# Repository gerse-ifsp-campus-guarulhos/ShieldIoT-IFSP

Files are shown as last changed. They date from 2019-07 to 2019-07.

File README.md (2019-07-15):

# ShieldIoT-IFSP

Licença: GNU GPL 2

Autores: [Pedro Igor Borçatti da Silva](https://github.com/pedro-ibs)

This program is free software; you can redistribute it and/or
modify it under the terms of the GNU General Public License as
published by the Free Software Foundation; version 2 of the
License.

This program is distributed in the hope that it will be useful,
but WITHOUT ANY WARRANTY; without even the implied warranty of
MERCHANTABILITY or FITNESS FOR A PARTICULAR PURPOSE.  See the
GNU General Public License for more details.

---

O SHIELD IoT-IFSP é uma placa didática criada para a plataforma NodeMCU (ESP8266) de baixo custo, desenvolvida para o ensino de lógica de programação aplicada à robótica e Iot (internet das coisas), cujo principal objetivo é facilitar o ensino de lógica de programação.

Neste Repositório se encontra todos os arquivos necessários para o **DESENVOLVIMENTO e DOCUMENTAÇÃO** para a **Shield IoT**, não Existe exemplos e programas testes para essa versão embora versões anteriores já tenham sido testadas (e falharam em algum ponto) no entanto esta versão está aparentemente está tudo certo, ela leva correções eletrônicas e de layout.

Na pasta [PCB](PCB/) estão os arquivos para fabricação da placa, tanto o [GERBER](PCB/GERBER/) para fabricação manufaturada, e um [PDF](PCB/PCB.pdf) para fabricação manual por transferência térmica. Em [Documentação](Documentação/) temos os arquivos referente ao circuito, lá encontrado o BOM (lista de componentes, e em formato ods feito pelo libreoffice), O [esquema elétrico](Documentação/esquematico.pdf) em pdf e o [arquivos do kicad](Documentação/Circuito/) e suas dependências.

# Uso dos pinos atual:
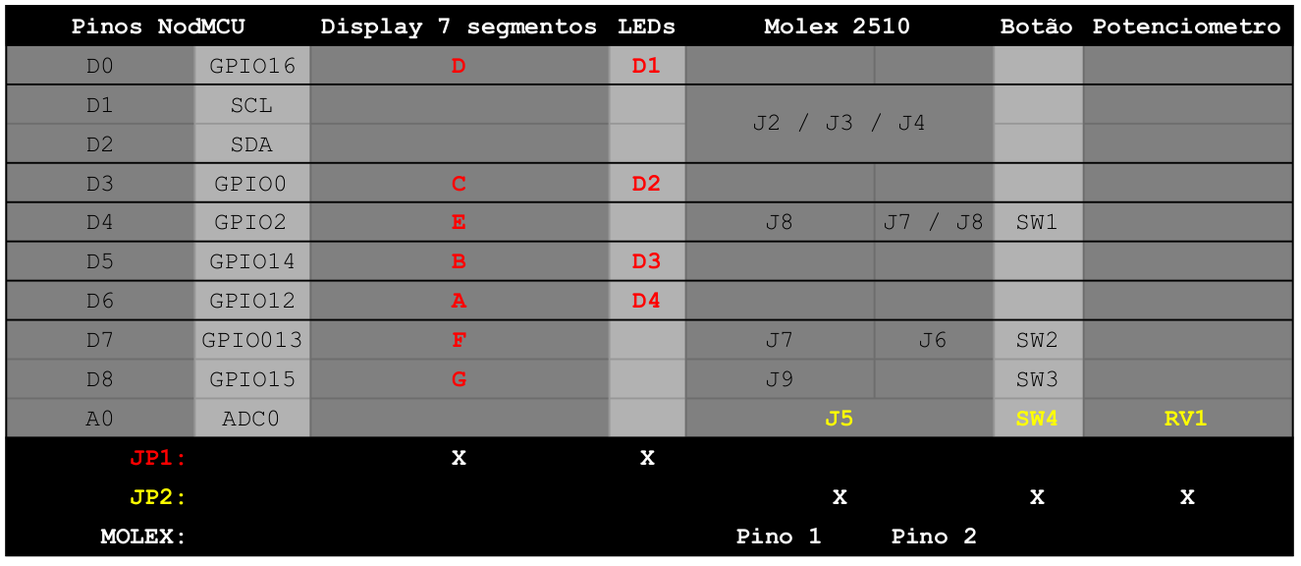
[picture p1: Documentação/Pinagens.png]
foto antiga


# O que precisa ser feio
* Testar placa, e todos os periféricos disponíveis para uso;
* Fazer um manual como a [Shield Edu-IFSP ](https://github.com/gerse-ifsp-campus-guarulhos/ShieldEdu-IFSP);
* programa testes como o [Exemplo da Shield Edu-IFSP](https://github.com/gerse-ifsp-campus-guarulhos/ShieldEdu-IFSP/tree/master/Exemplos);
* Criar artigos e publicações.

# Versão antiga

Está é a foto da versão antiga da placa porem existe em algum lugar no gerse a mesma versão dos arquivos desse repositório construída por transferência térmica

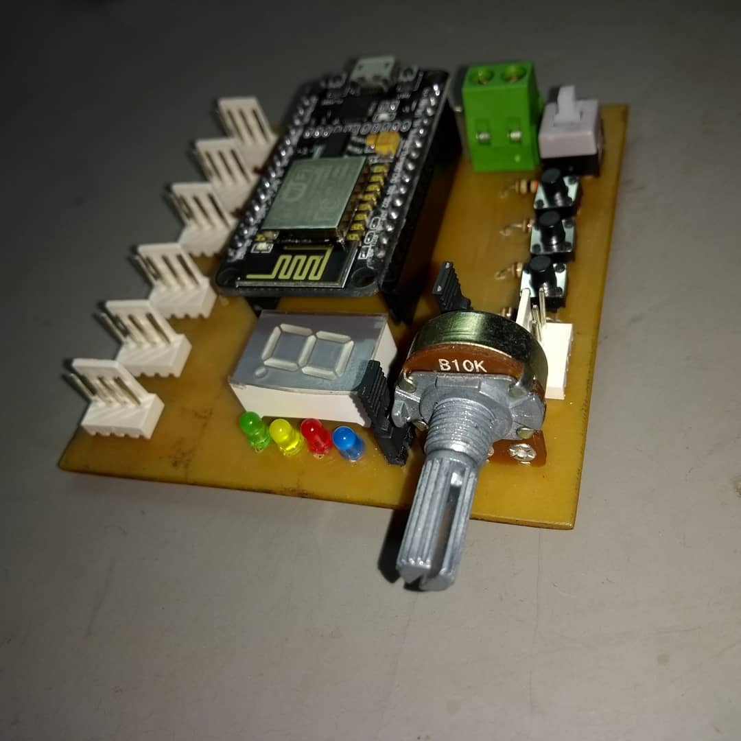
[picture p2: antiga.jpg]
versão antiga


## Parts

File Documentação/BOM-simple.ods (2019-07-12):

Referencia | Valor | Footprint | Quantidade
D1 – D4 | LED_ALT | MyFootprint:LED_D3.0mm | 4
D5 | 1N4007 | Diodes_THT:D_A-405_P5.08mm_Vertical_AnodeUp | 1
IC1 | NODEMCU | MyFootprint:NODEMCU2 | 1
J1 | VCC | MyFootprint:AK300-2 | 1
J2 - J4 | I2C | MyFootprint:molex_2510 | 3
J5 | VAIN | MyFootprint:molex_2510 | 1
J6 - J8 | OUT | MyFootprint:molex_2510 | 3
JP1, JP2 | JUMP3 | MyFootprint:Pin_Header_Straight_1x03 | 2
R2, R3 | 10K | MyFootprint:Resistor_Vertical_RM7mm | 2
R1 - R13 | 10K | Resistors_THT:R_Axial_DIN0207_L6.3mm_D2.5mm_P10.16mm_Horizontal | 4
R5 - R11 | 470 | MyFootprint:Resistor_Vertical_RM7mm | 7
RV1 | R_POT | MyFootprint:Potentiometer_Alps-RK16-single_largePads | 1
SW1 | BT1 | MyFootprint:BUTTON2P | 1
SW2, SW4 | BT2 | MyFootprint:BUTTON2P | 2
SW3 | SP6T | MyFootprint:SW_PUSH_x2 | 1
U1 | KCSA02-107 | MyFootprint:7SegmentLED_LTS6760_LTS6780-2 | 1

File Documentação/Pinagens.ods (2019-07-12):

Pinos NodMCU |  | Display 7 segmentos | LEDs | Molex 2510 |  | Botão | Potenciometro
D0 | GPIO16 | D | D1
D1 | SCL |  |  | J2 / J3 / J4
D2 | SDA
D3 | GPIO0 | C | D2
D4 | GPIO2 | E |  | J8 | J7 / J8 | SW1
D5 | GPIO14 | B | D3
D6 | GPIO12 | A | D4
D7 | GPIO013 | F |  | J7 | J6 | SW2
D8 | GPIO15 | G |  | J9 |  | SW3
A0 | ADC0 |  |  | J5 |  | SW4 | RV1
JP1: |  | X | X
JP2: |  |  |  | X |  | X | X
MOLEX: |  |  |  | Pino 1 | Pino 2

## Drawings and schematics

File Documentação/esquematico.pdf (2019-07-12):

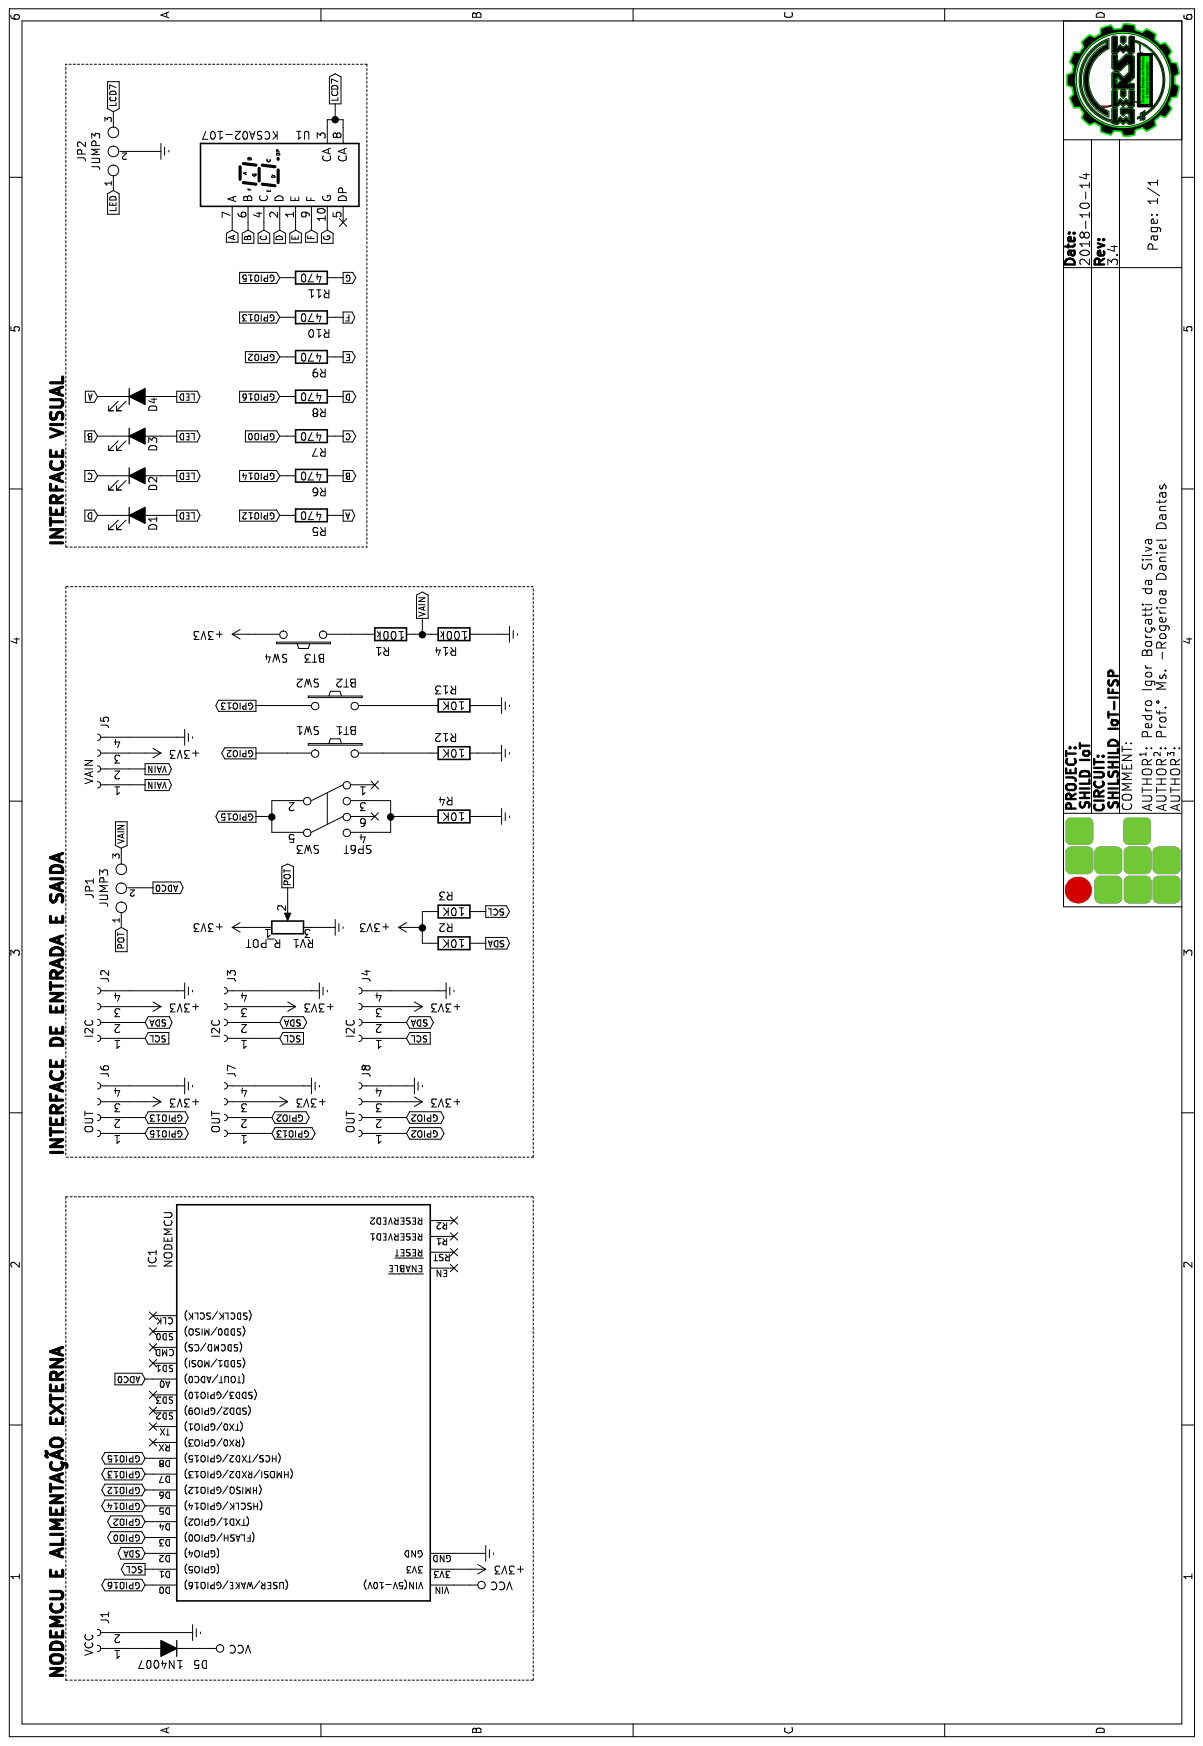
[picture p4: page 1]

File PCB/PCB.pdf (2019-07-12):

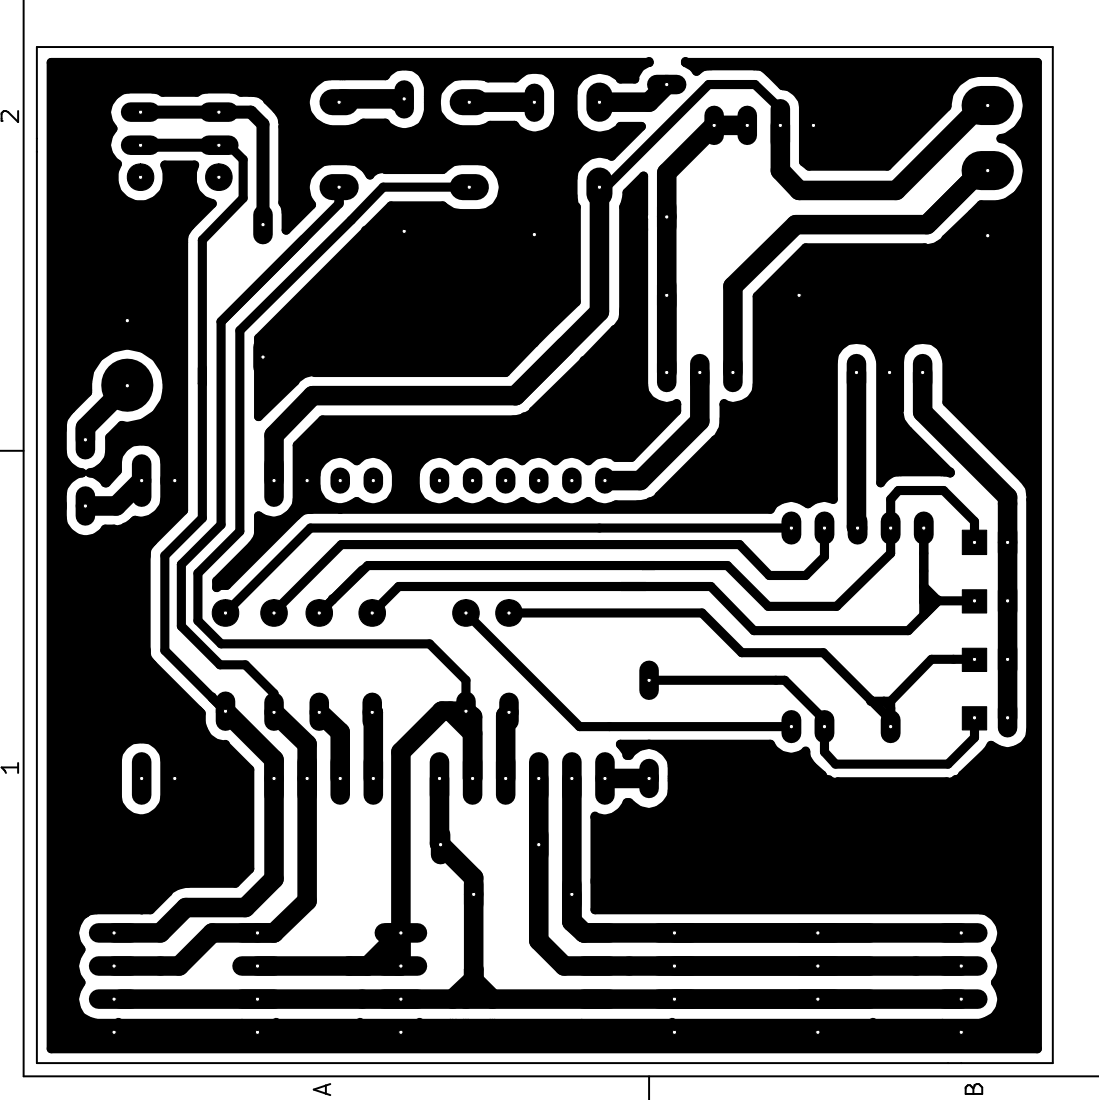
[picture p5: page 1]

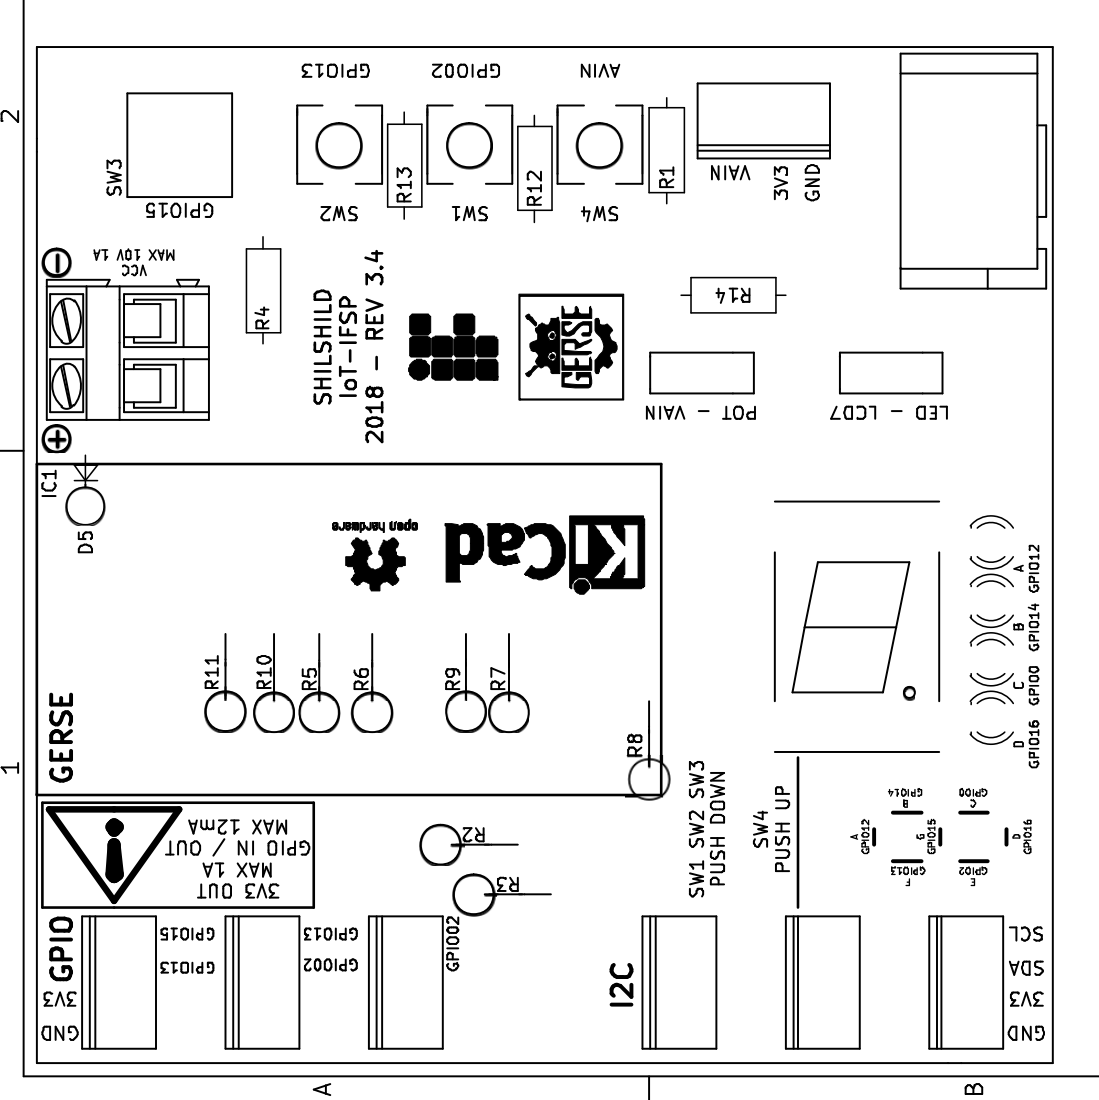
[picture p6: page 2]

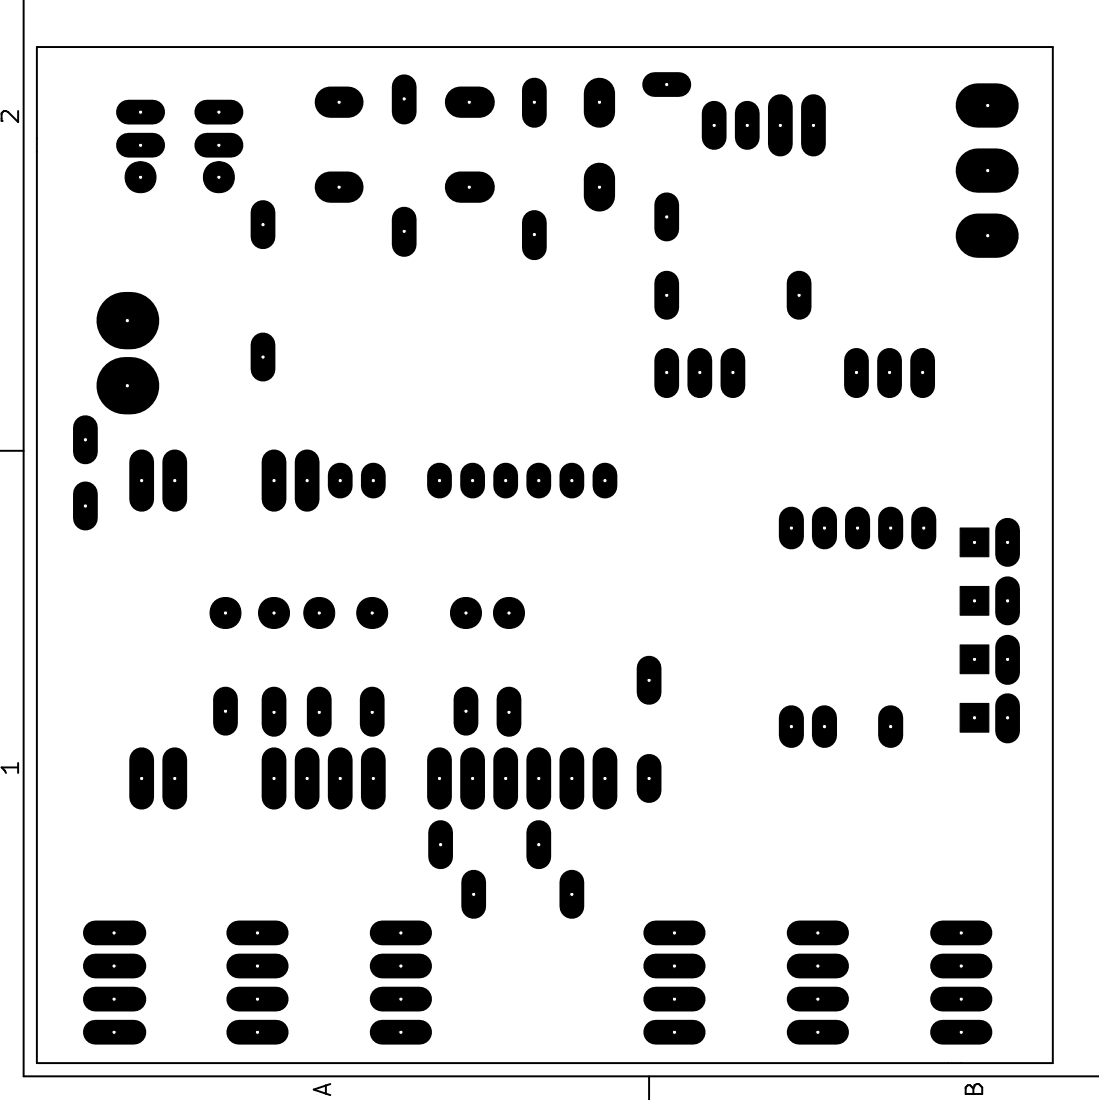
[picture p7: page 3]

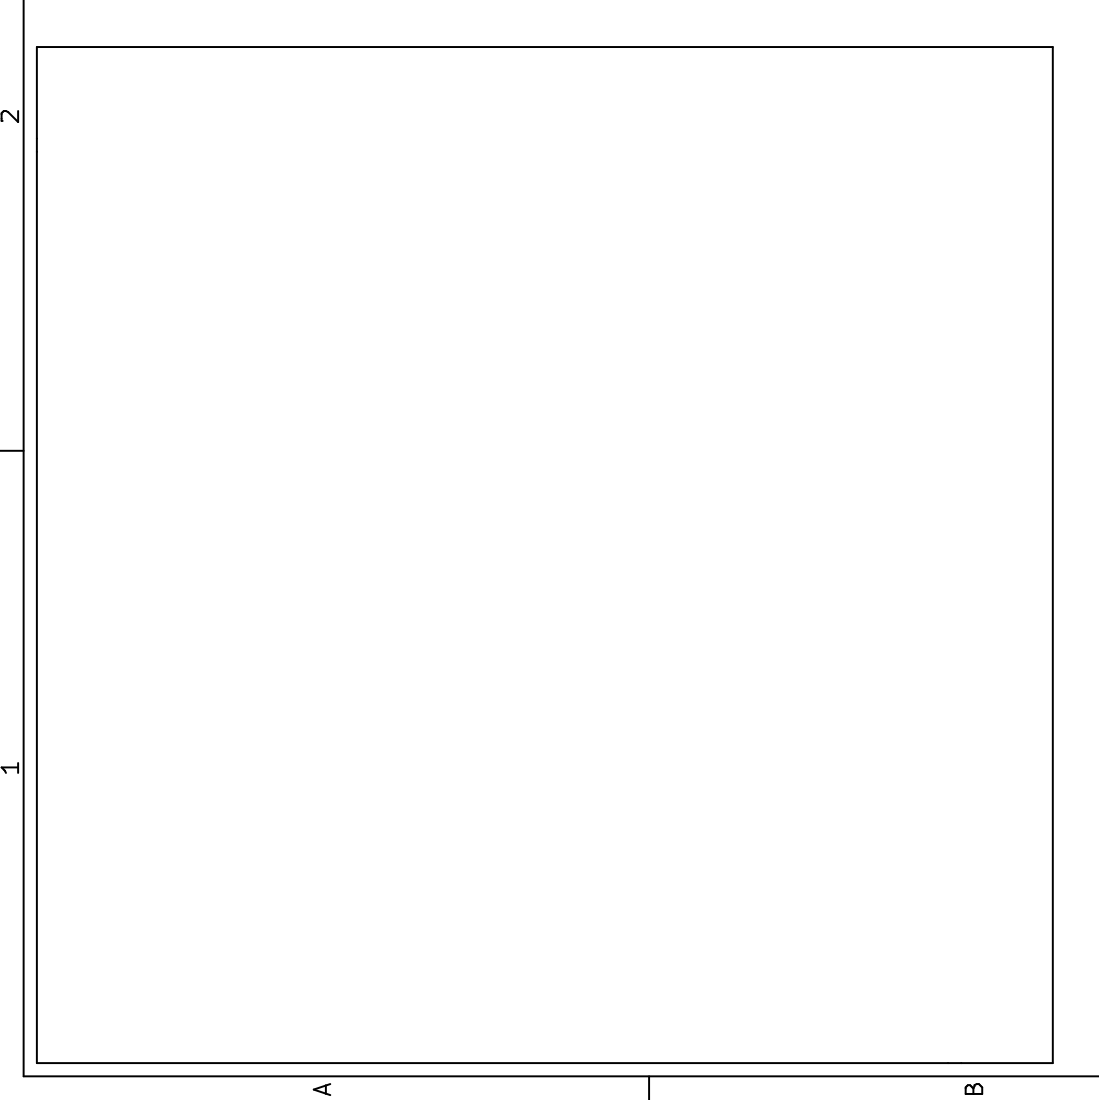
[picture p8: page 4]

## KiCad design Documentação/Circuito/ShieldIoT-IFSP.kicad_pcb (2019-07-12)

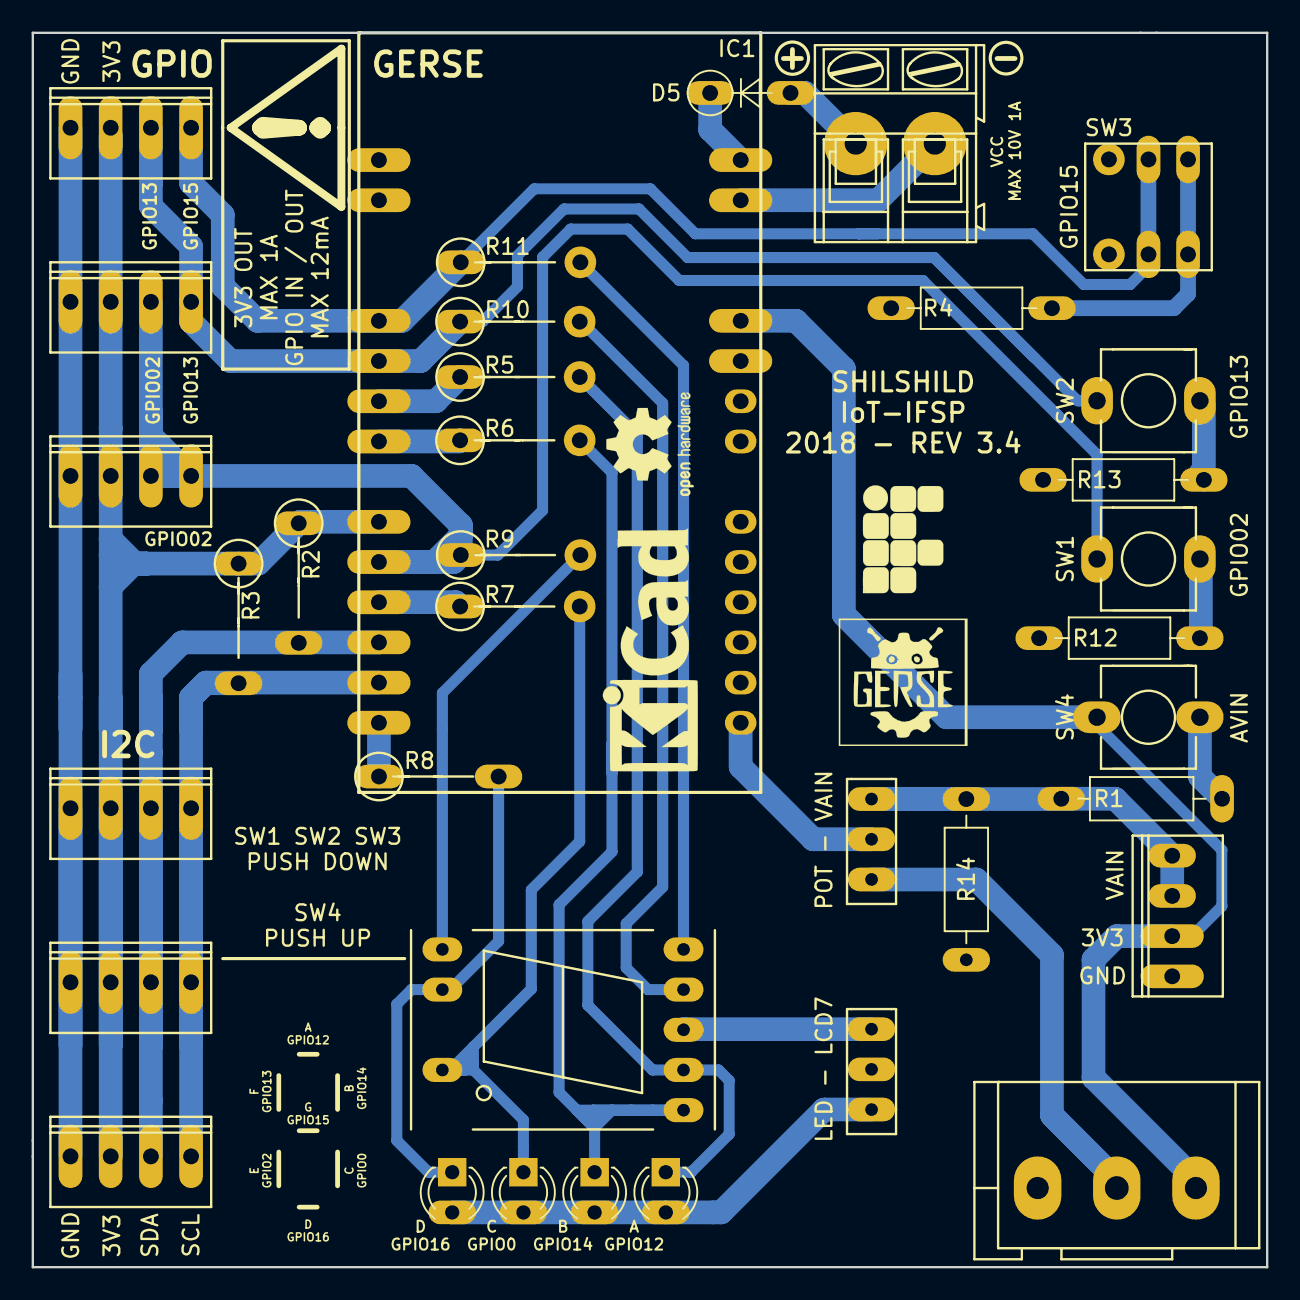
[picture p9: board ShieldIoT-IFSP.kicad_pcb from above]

Board: 2 copper layers, 78.0 x 78.0 mm, 36 parts (0 on the bottom side), 28 nets.

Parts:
D1, D2, D3, D4: LED_ALT; LED_D3.0mm
D5: 1N4007; D_A-405_P5.08mm_Vertical_AnodeUp
IC1: NODEMCU
J1: VCC; AK300-2
J2, J3, J4: I2C; molex_2510
J5: VAIN; molex_2510
J6, J7, J8: OUT; molex_2510
JP1, JP2: JUMP3; Pin_Header_Straight_1x03
R1, R14: 100k; R_Axial_DIN0207_L6.3mm_D2.5mm_P10.16mm_Horizontal
R2, R3: 10K; Resistor_Vertical_RM7mm
R4, R12, R13: 10K; R_Axial_DIN0207_L6.3mm_D2.5mm_P10.16mm_Horizontal
R5, R6, R7, R8, R9, R10, R11: 470; Resistor_Vertical_RM7mm
RV1: R_POT; Potentiometer_Alps-RK16-single_largePads
SW1: BT1; MySW_PUSH_6mm_H4.3mm
SW2: BT2; MySW_PUSH_6mm_H4.3mm
SW3: SP6T; SW_PUSH_x2
SW4: BT3; MySW_PUSH_6mm_H4.3mm
U1: KCSA02-107; 7SegmentLED_LTS6760_LTS6780-2

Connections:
+3V3: IC1.3V3, J2.3, J3.3, J4.3, J5.3, J6.3, J7.3, J8.3, R2.1, R3.1, RV1.1, SW4.1
A: D4.1, R5.2, U1.7
ADC0: IC1.A0, JP1.2
B: D3.1, R6.2, U1.6
C: D2.1, R7.2, U1.4
D: D1.1, U1.2
E: R9.2, U1.1
Earth: IC1.GND, J1.2, J2.4, J3.4, J4.4, J5.4, J6.4, J7.4, J8.4, JP2.2, R4.2, R12.2, R13.2, R14.2, RV1.3
F: R10.2, U1.9
G: R11.2, U1.10
GPIO0: IC1.D3, R7.1
GPIO2: IC1.D4, J7.2, J8.1, J8.2, R9.1, SW1.1
GPIO12: IC1.D6, R5.1
GPIO13: IC1.D7, J6.2, J7.1, R10.1, SW2.1
GPIO14: IC1.D5, R6.1
GPIO15: IC1.D8, J6.1, R11.1, SW3.2, SW3.5
LCD7: JP2.3, U1.8
LED: D1.2, D2.2, D3.2, D4.2, JP2.1
unnamed: D5.2, J1.1
unnamed: R1.1, SW4.2
unnamed: R4.1, SW3.3, SW3.4
unnamed: R12.1, SW1.2
unnamed: R13.1, SW2.2
POT: JP1.1, RV1.2
SCL: IC1.D1, J2.1, J3.1, J4.1, R3.2
SDA: IC1.D2, J2.2, J3.2, J4.2, R2.2
VAIN: J5.1, J5.2, JP1.3, R1.2, R14.1
VCC: D5.1, IC1.VIN
